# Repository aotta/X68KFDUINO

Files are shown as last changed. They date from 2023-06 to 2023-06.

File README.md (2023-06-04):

# X68KFDUINO
External floppy disk adapter for Sharp X68000, based on Arduino Nano

Use 2 buttons to give X68k the insert/eject signals: you have to eject the virtual floppy (turn off green led) when led flashes, select the image on HxC/Gotek, then re-insert the virtual floppy (Green led re-turned on).
This for disk 1 or 2, as needed.

More info on nfg.forums : https://nfggames.com/forum2/index.php?topic=7225.0

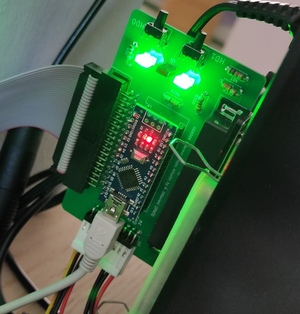
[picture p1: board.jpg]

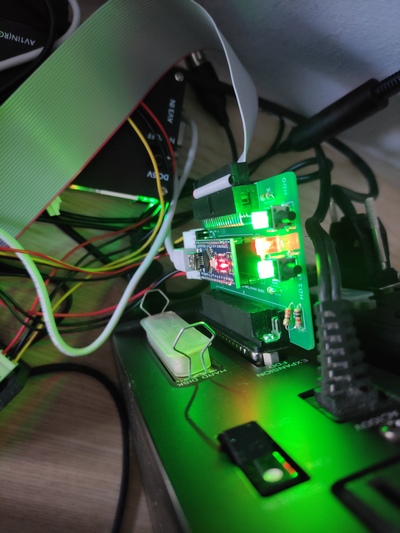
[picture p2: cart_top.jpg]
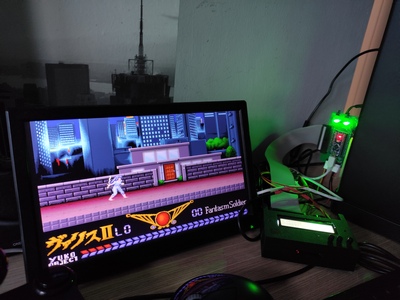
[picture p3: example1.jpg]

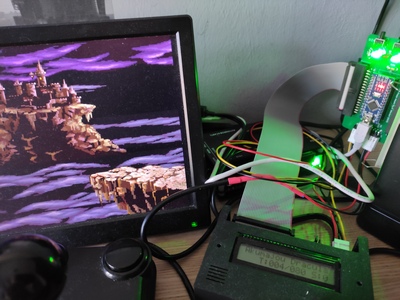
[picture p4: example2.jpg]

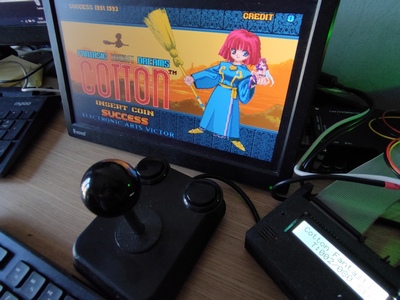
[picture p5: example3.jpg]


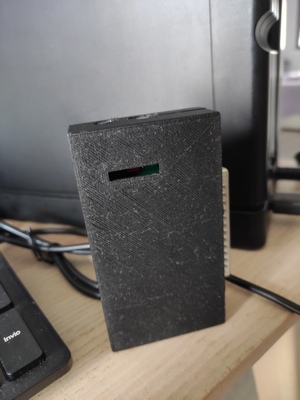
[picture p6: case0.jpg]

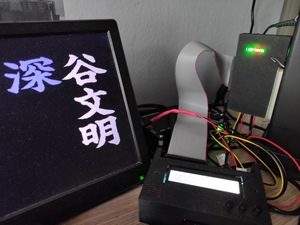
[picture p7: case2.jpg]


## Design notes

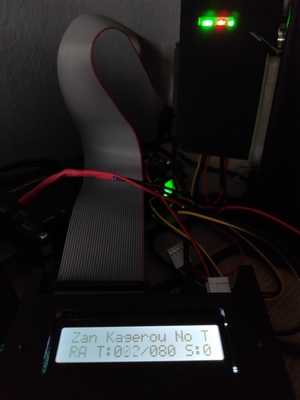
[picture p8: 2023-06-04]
case1.jpg

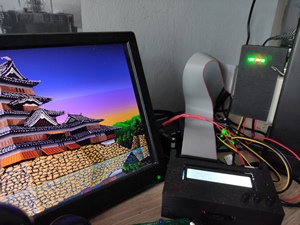
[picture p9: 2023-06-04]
case3.jpg

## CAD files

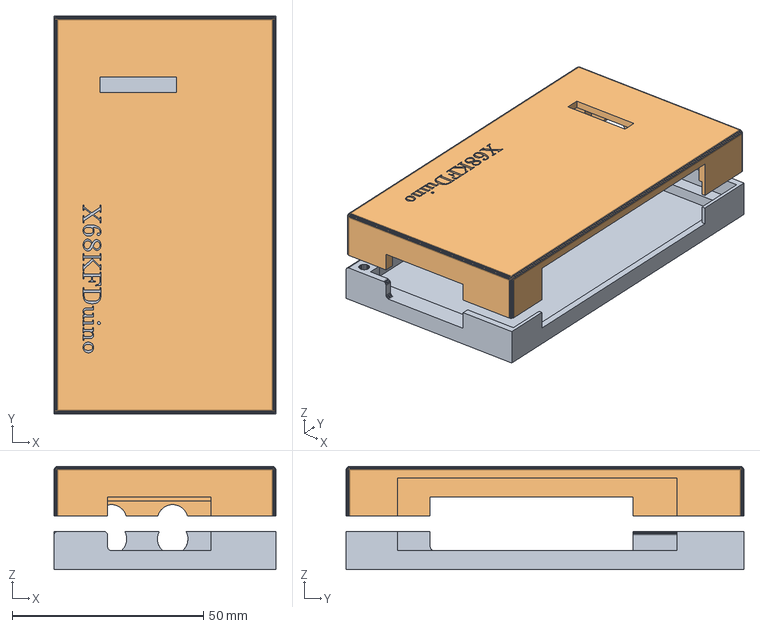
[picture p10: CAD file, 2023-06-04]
3DPrint/X68KFDuino.FCStd
58.0 x 104.0 x 27.0 mm
Bottom3D
Top3D

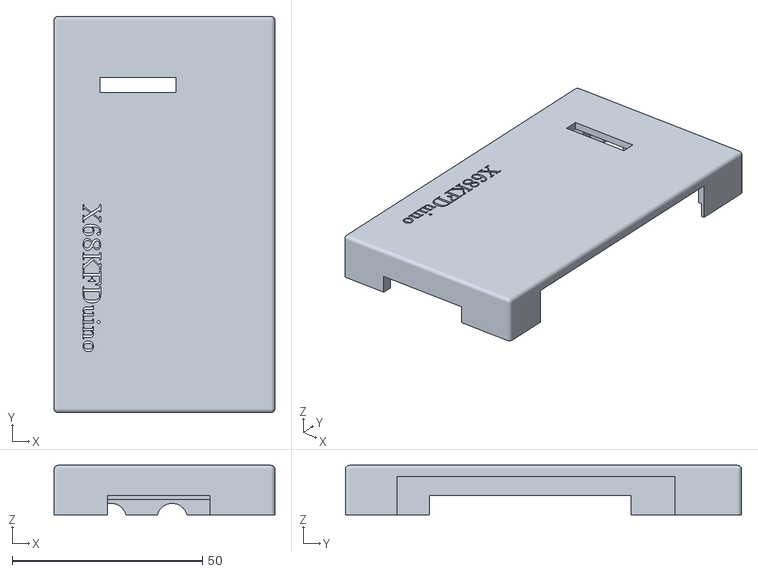
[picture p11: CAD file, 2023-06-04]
3DPrint/X68KFDuino-Top_Print.stl
58.0 x 104.0 x 13.0

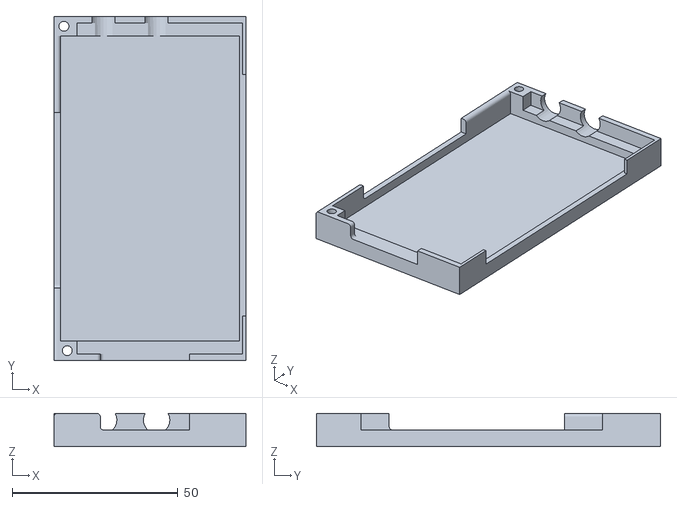
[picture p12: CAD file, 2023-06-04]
3DPrint/X68KFDuino-Bottom_Print.stl
58.0 x 104.0 x 10.0

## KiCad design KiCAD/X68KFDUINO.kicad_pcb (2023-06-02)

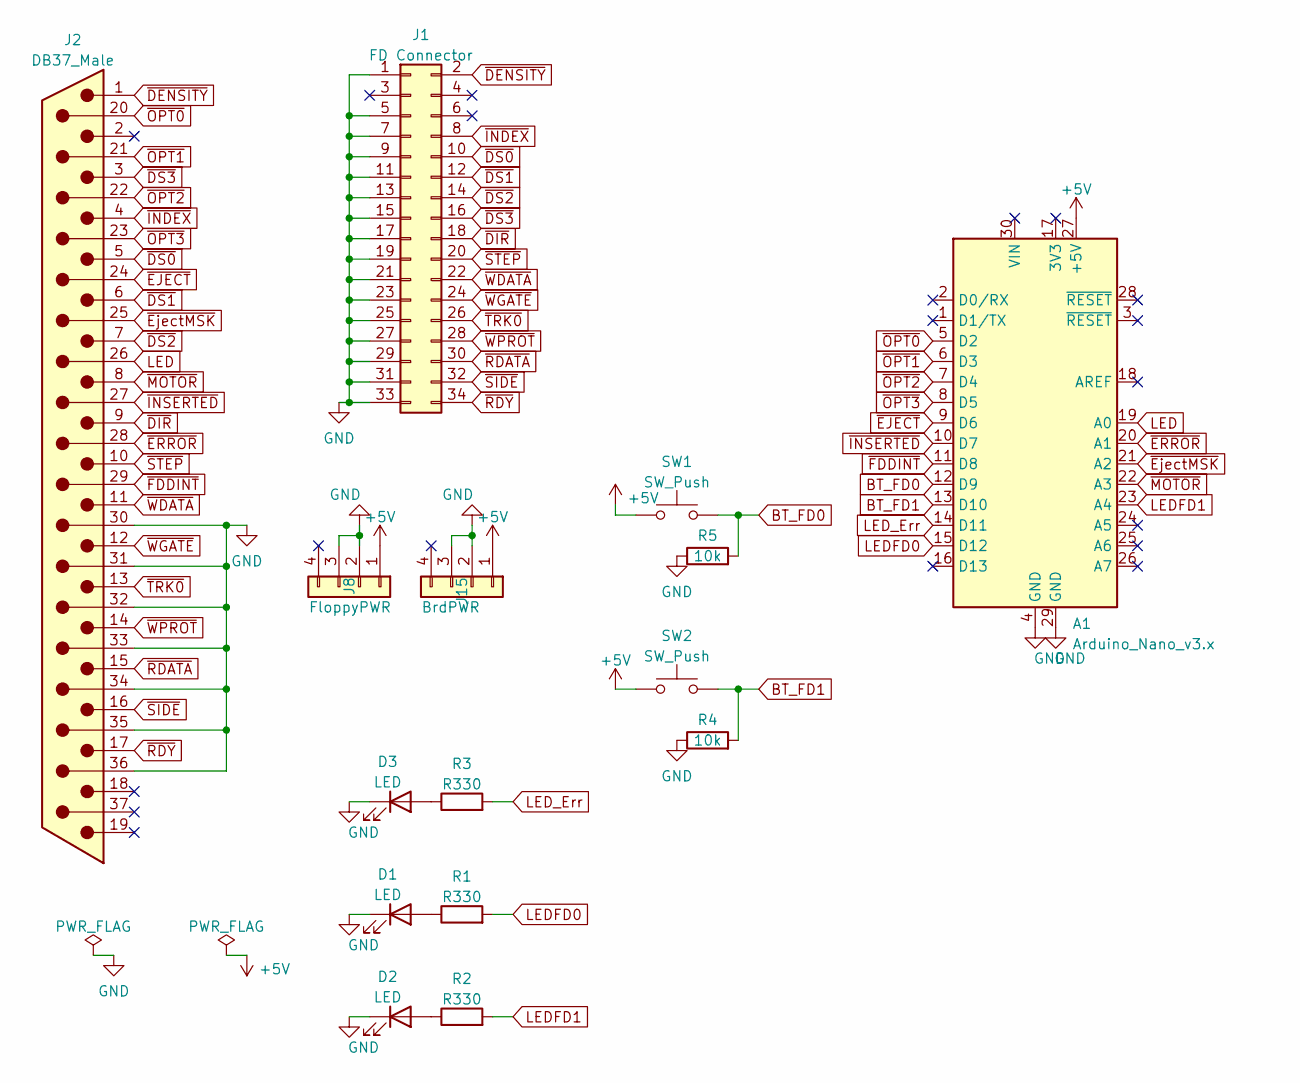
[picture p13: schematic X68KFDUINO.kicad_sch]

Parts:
A1: Arduino_Nano_v3.x; Arduino_Nano
D1, D2, D3: LED; LED_D3.0mm
J1: FD Connector; IDC-Header_2x17_P2.54mm_Horizontal
J2: DB37_Male; DSUB-37_Male_Horizontal_P2.77x2.84mm_EdgePinOffset4.94mm_Ho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
J8: FloppyPWR; PinHeader_1x04_P2.54mm_Horizontal
J15: BrdPWR; PinHeader_1x04_P2.54mm_Horizontal
R1, R2, R3: R330; R_Axial_DIN0207_L6.3mm_D2.5mm_P7.62mm_Horizontal
R4, R5: 10k; R_Axial_DIN0207_L6.3mm_D2.5mm_P7.62mm_Horizontal
SW1, SW2: SW_Push; SW_Tactile_SPST_Angled_PTS645Vx83-2LFS

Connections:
+5V: A1.27 (+5V), J8.1, J15.1, SW1.1, SW2.1
BT_FD0: A1.12 (D9), R5.2, SW1.2
BT_FD1: A1.13 (D10), R4.2, SW2.2
GND: A1.4 (GND), A1.29 (GND), D1.1 (K), D2.1 (K), D3.1 (K), J1.1, J1.5, J1.7, J1.9, J1.11, J1.13, J1.15, J1.17, J1.19, J1.21, J1.23, J1.25, J1.27, J1.29, J1.31, J1.33, J2.30, J2.31, J2.32, J2.33, J2.34, J2.35, J2.36, J8.2, J8.3, J15.2, J15.3, R4.1, R5.1
LED: A1.19 (A0), J2.26
LEDFD0: A1.15 (D12), R1.2
LEDFD1: A1.23 (A4), R2.2
LED_Err: A1.14 (D11), R3.2
unnamed: D1.2 (A), R1.1
unnamed: D2.2 (A), R2.1
unnamed: D3.2 (A), R3.1
~DENSITY: J1.2, J2.1
~DIR: J1.18, J2.9
~DS0: J1.10, J2.5
~DS1: J1.12, J2.6
~DS2: J1.14, J2.7
~DS3: J1.16, J2.3
~EJECT: A1.9 (D6), J2.24
~ERROR: A1.20 (A1), J2.28
~EjectMSK: A1.21 (A2), J2.25
~FDDINT: A1.11 (D8), J2.29
~INDEX: J1.8, J2.4
~INSERTED: A1.10 (D7), J2.27
~MOTOR: A1.22 (A3), J2.8
~OPT0: A1.5 (D2), J2.20
~OPT1: A1.6 (D3), J2.21
~OPT2: A1.7 (D4), J2.22
~OPT3: A1.8 (D5), J2.23
~RDATA: J1.30, J2.15
~RDY: J1.34, J2.17
~SIDE: J1.32, J2.16
~STEP: J1.20, J2.10
~TRK0: J1.26, J2.13
~WDATA: J1.22, J2.11
~WGATE: J1.24, J2.12
~WPROT: J1.28, J2.14

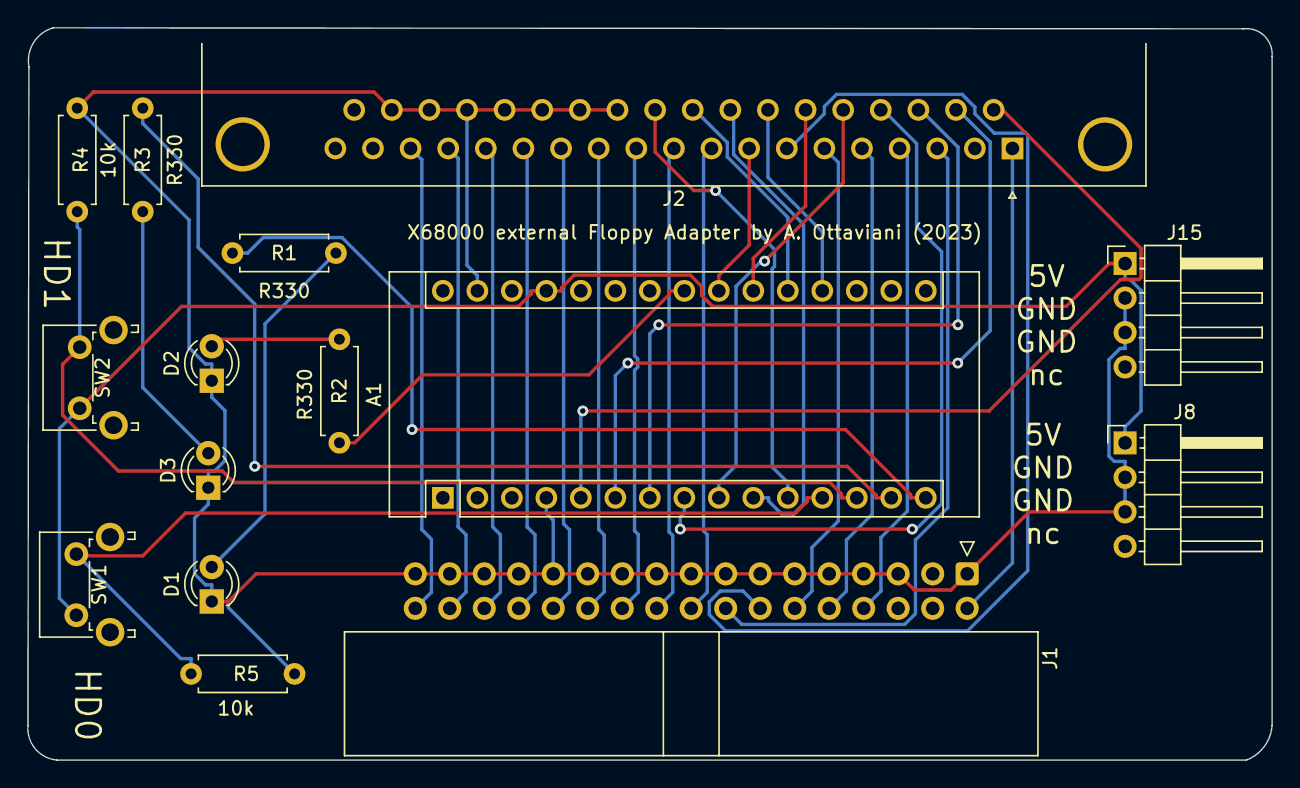
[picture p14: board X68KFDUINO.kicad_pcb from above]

Board: 2 copper layers, 91.6 x 53.9 mm, 15 parts (0 on the bottom side), 36 nets.

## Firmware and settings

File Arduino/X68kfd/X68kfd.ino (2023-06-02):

/*
 * X68KFDINO - External FD adapter for Sharp X68000
 * by Andrea Ottaviani june 2023
 * 
 * 
Access/Write strobe :

/OPTION_SEL_X : "Chip select" for the extra functions of drive DSX (X: 0-3)

Input / functions signals :

/EJECT_FUNC : If this signal is low when OPTION_SEL_X is asserted, the disk will be ejected.
/LOCK_FUNC (Eject MSK?): If this signal is low when OPTION_SEL_X is asserted, the disk will be locked (eject button off). If this signal is high when OPTION_SEL_X is asserted the disk will be unlocked (eject button on).
/BLINK_FUNC : If this signal is low when OPTION_SEL_X is asserted, the LED blink. If this signal is high when OPTION_SEL_X is asserted, the LED stop blinking.

Output signals (drive status):

/DISK_IN_DRIVE : when OPTION_SEL_X is asserted : Low = a disk in the drive. High = No disk.
/INSERT_FAULT : when OPTION_SEL_X is asserted : Low = a disk insert failure occured . High = No problem. This status is cleared at the rising edge of OPTION_SEL_X.

Output signal (Interrupt line):

/INT : Interrupt line : This signal is activated at each disk status change (inserted/ejected). The interrupt is cleared at the rising edge of /OPTION_SEL_X. (Note : more than one drive can activate this line in the same time -> Softwares scan all disk drive at each /INT assertion).

Note 1: For proper operation all output should be able to drive 5/150=33mA since 150 ohms pull-up are used.
Note 2: The X68000 /OPTION_SEL_X assertion duration is ~2.5us per access. This can depend of the software, the CPU speed.
 */


//Cablage
#define OPT0                2  // Set D2 as OPT0 Read strobe
#define OPT1                3  // Set D3 as OPT1 Read strobe
#define OPT2                4  // Set D4 as OPT2 Read strobe
#define OPT3                5  // Set D5 as OPT3 Read strobe
#define Eject               6  // Set D6 as Eject Read strobe
#define Inserted            7 // Set D7 as Inserted Read strobe
#define FDDINT              8   // Set D8 as FD Interrupt Read strobe
#define BT_FD0              9  // Set D9 as Button FD0 Read strobe
#define BT_FD1             10  // Set D10 as Button FD1 Read strobe
#define LED_RED            11  // Set D11 as LED_RED output (RED LED)
#define LEDFD0            12  // Set D12 as LED FD0 output (Green LED)
#define LED_BLINK          A0  // Set A0 as LED (Blink) output
#define Error              A1  // Set A1 as Error Read strobe
#define EjectMSK           A2  // Set A2 as EjectMSK Read strobe
#define Motor              A3  // Set A3 as Motor Read strobe
#define LEDFD1             A4  // Set A4 as LED FD1 output (Green LED)


void setup() {
  // put your setup code here, to run once:
  // initialize digital pin 13 as an output.
  pinMode(OPT0, INPUT);
  pinMode(OPT1, INPUT);
  pinMode(OPT2, INPUT);
  pinMode(OPT3, INPUT);
  pinMode(Eject, INPUT);
  pinMode(BT_FD0, INPUT);
  pinMode(BT_FD1, INPUT);
  pinMode(LED_BLINK, INPUT); // Blink
  pinMode(EjectMSK, INPUT); // LOCK (Red led)
  pinMode(Motor, INPUT); // 
  pinMode(Inserted, OUTPUT);
  pinMode(FDDINT, OUTPUT);
  pinMode(LED_RED, OUTPUT); // used for LED LOCK, Red light
  pinMode(LEDFD0, OUTPUT);
  pinMode(Error, OUTPUT);
  pinMode(LEDFD1, OUTPUT);

  Serial.begin(115200);

}

void loop() {
  unsigned int LDF0=0; // 0=unlocked, 1=locked
  unsigned int LDF1=0; // 0=unlocked, 1=locked
  unsigned int DF0=1; // 0=eject, 1=insert, 2=lock, 3=blink
  unsigned int DF1=1; // 0=eject, 1=insert, 2=lock, 3=blink
  unsigned int bit0Eject=0;
  unsigned int bit0Msk=0;
  unsigned int bit0Blink=0;
  unsigned int bit1Eject=0;
  unsigned int bit1Msk=0;
  unsigned int bit1Blink=0;
  unsigned int dint=30; //30 ok x drakula e ajax
  unsigned int dblink=50;  //50 ok x drakula e ajax
  
  // put your main code here, to run repeatedly:

 while(1) {

   digitalWrite(Inserted,HIGH);
  // digitalWrite(Error,LOW); needed for nemesis 90 kay?
 
   if ((digitalRead(BT_FD0)==HIGH)&&(LDF0==0)) {
     bit0Blink=0;
     if (DF0==1) {
        DF0=0;
      } else {
        DF0=1;
      }
    Serial.print("DF0:");Serial.println(DF0);
    delay(600);
    }

  if ((digitalRead(BT_FD1)==HIGH)&&(LDF1==0)) {
      bit1Blink=0;
      if (DF1==1) {
        DF1=0;
      } else {
        DF1=1;
      }
    Serial.print("DF1:");Serial.println(DF1);
    delay(600);
    }

   if (digitalRead(OPT0)==LOW) {
     if (digitalRead(Eject)==LOW) {
       DF0=0;
       bit0Blink=0;
       Serial.print("Ej 0-");
    }
    
    if (digitalRead(EjectMSK)==LOW) {
      LDF0=1;
    //  Serial.println("MSK0");
      digitalWrite(LED_RED,HIGH);
    } else {
      LDF0=0;
      digitalWrite(LED_RED,LOW);
    }
 
    if (digitalRead(LED_BLINK)==LOW) {
       bit0Blink=1;
       digitalWrite(LEDFD0,LOW); 
        delay(dblink);   // low for A-JAX
       digitalWrite(LEDFD0,HIGH);
     //  Serial.println("Blk 0-"); 
    }

    
    if (DF0==0) {
       digitalWrite(FDDINT,LOW);
       digitalWrite(LEDFD0,LOW);
      } else {
       if (bit0Blink==0) {
         digitalWrite(Inserted,LOW);
       //  Serial.print("df0-IN");
         digitalWrite(Error,HIGH);
         digitalWrite(FDDINT,HIGH);
         digitalWrite(LEDFD0,HIGH);
         delay(dint); // to receipt from X68k?
             } else {
          digitalWrite(FDDINT,LOW);
          digitalWrite(LEDFD0,HIGH); 
         }
      }
  }  // opt 0

 if (digitalRead(OPT1)==LOW) {
  if (digitalRead(Eject)==LOW) {
      DF1=0;
      bit1Blink=0;
      Serial.print("Ej 1-");
    }
    
  if (digitalRead(EjectMSK)==LOW) {
      LDF1=1;
    //  Serial.println("MSK1");
    digitalWrite(LED_RED,HIGH);
  } else {
      LDF1=0;
      digitalWrite(LED_RED,LOW);
    }
    
  if (digitalRead(LED_BLINK)==LOW) {
       bit1Blink=1;
       digitalWrite(LEDFD1,LOW); 
     delay(dblink);
      // digitalWrite(LEDFD1,HIGH); 
      //Serial.print("Blk 1-");
       }
    
       if (DF1==0) {
       digitalWrite(FDDINT,LOW);
       digitalWrite(LEDFD1,LOW);
      } else {
       if (bit1Blink==0) {
         digitalWrite(Inserted,LOW);
        //  Serial.print("df1-IN");
         digitalWrite(Error,HIGH);
         digitalWrite(FDDINT,HIGH);
         digitalWrite(LEDFD1,HIGH);
         delay(dint); // to receipt from X68k?
          } else {
          digitalWrite(LEDFD1,HIGH); 
         }
      }
  
  } //opt1
  
 } //while
 
}
